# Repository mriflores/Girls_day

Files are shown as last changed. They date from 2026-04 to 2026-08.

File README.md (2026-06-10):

# 433MHz RF Communication Project with ID Filtering & Servo Control

This project implements a wireless communication system between two Arduino boards using 433MHz Radio Frequency modules. It features a custom ID filtering system to ensure messages are processed only by the intended receiver, and allows for remote control of a servo motor.

---

## Hardware Configuration

### Components Required
* **Microcontrollers:** 2x Arduino Uno.
* **RF Kit:** 2x 433MHz Transmitter (FS1000A), 1x 433MHz Receiver (XY-MX-5V).
* **Actuator:** 1x Servo Motor (e.g., SG90, MG996R).
* **Antennas:** 4x 17.3 cm copper wires (Required for range beyond 10cm).

### RF Wiring Diagram

| RF Module | Arduino Pin | Description |
| :--- | :--- | :--- |
| **Transmitter DATA** | D12 | Data Output |
| **Transmitter VCC** | 5V | Power (Up to 12V for range) |
| **Transmitter GND** | GND | Ground |
| **Receiver DATA** | D11 | Data Input |
| **Receiver VCC** | 5V | Power (Must be stable 5V) |
| **Receiver GND** | GND | Ground |

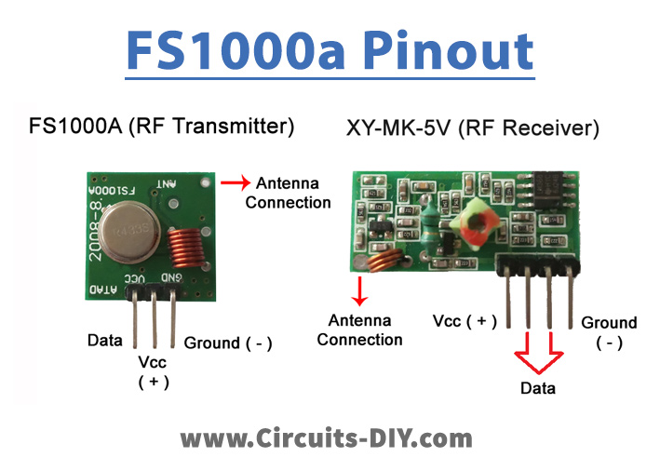
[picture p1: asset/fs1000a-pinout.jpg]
Pinout


### Servo Wiring Diagram

| Servo | Arduino Pin | Description |
| :--- | :--- | :--- |
| **Signal (Orange/Yellow)**| D2 | PWM Control Signal |
| **VCC (Red)** | 5V | Power (External power recommended for larger servos) |
| **GND (Brown/Black)** | GND | Ground |

---

## Technical Implementation & Dependencies

The system relies on specific libraries to manage the communication and motor control without hardware timer conflicts:

* **RadioHead (RH_ASK):** Handles the physical layer bit-streaming, preamble, and CRC error checking for the RF modules. It inherently relies on Arduino's Timer 1.
* **ServoTimer2:** Manages the PWM signals for the servo motor. Using this library instead of the standard Arduino `Servo.h` is necessary to prevent Timer 1 conflicts, ensuring both RF communication and servo movements work seamlessly together.

---

## Features

* **Targeted Messaging:** Uses custom ID prefixes to ensure that only the designated receiver acts on a broadcasted message, ignoring irrelevant data.
* **Remote Actuation:** Wirelessly controls a servo motor, interpreting text strings to execute specific physical movements.
* **Dynamic Pulse Mapping:** Automatically maps standard angle values (0-180 degrees) to microsecond pulse widths for accurate servo positioning.

---

## Command Protocol

The transmitter must format strings with a specific structure for the receiver to validate and act upon them. The structure is: 

`[RECEIVER_ID] [COMMAND]`

### Example Usage:
In this project, the Receiver's ID is set to `100`. Through the Serial Monitor, you can send the following commands:

* **`100 OPEN`**: The receiver parses the ID, confirms a match, and moves the servo to the 90-degree position.
* **`100 CLOSE`**: The receiver parses the ID, confirms a match, and returns the servo to the 0-degree position.

Any message received with an incorrect ID (e.g., `300 OPEN` or just `OPEN`) will be completely ignored by the receiving node.

---

## Important Notes
* **Power Supply:** If the Arduino resets or the RF receiver stops working when the servo moves, it is highly recommended to power the servo with a separate 5V power supply. Remember to connect the ground (GND) of the external power supply to the Arduino's GND.

---

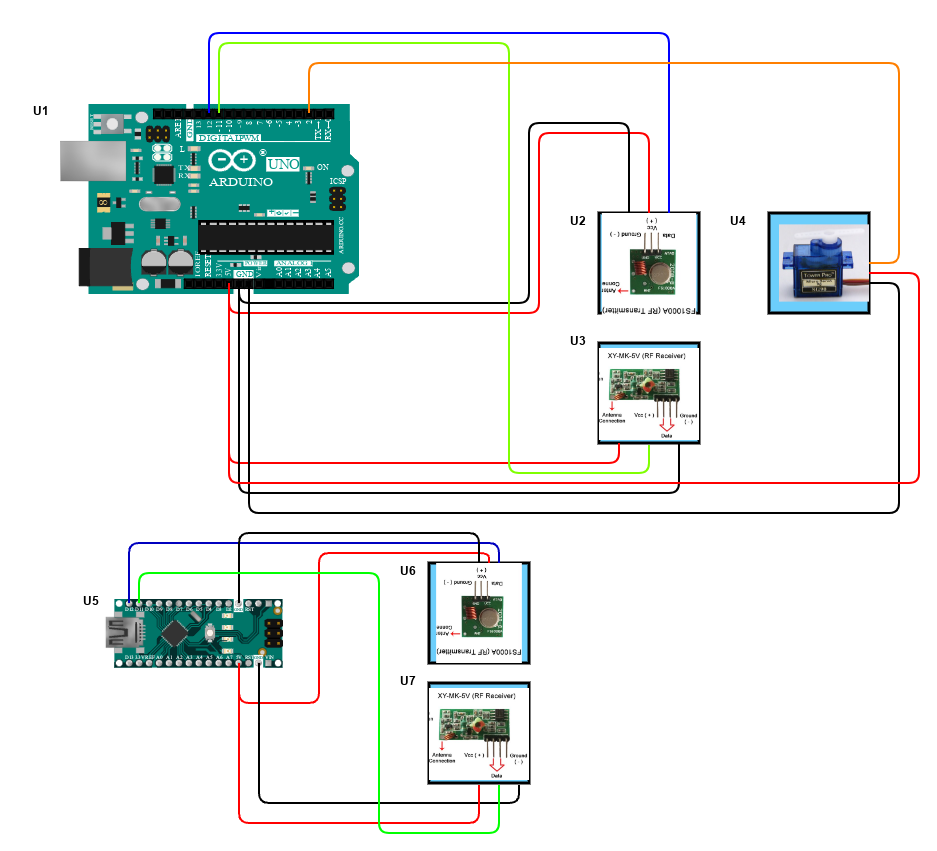
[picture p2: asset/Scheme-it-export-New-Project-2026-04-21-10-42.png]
Schematic Overview


The uploaded image illustrates the specific wiring connections for two separate microcontroller nodes capable of two-way RF communication.

**Node 1** (Top Section)
    This node acts as the primary controller equipped with actuation capabilities.

* Microcontroller: Arduino Uno (U1).

* RF Transmitter (U2 - FS1000A): The Data pin is wired to digital pin D12 (blue wire).

* RF Receiver (U3 - XY-MK-5V): The Data pin is wired to digital pin D11 (green wire).

* Servo Motor (U4): The PWM signal pin is wired to digital pin D2 (orange wire).

Power: All three peripherals (U2, U3, U4) share common 5V (red wires) and Ground (black wires) connections drawn directly from the Arduino Uno.

**Node 2** (Bottom Section)
    This node acts as the secondary transceiver.

* Microcontroller: A compact Arduino board, such as a Nano or Micro (U5).

* RF Transmitter (U6 - FS1000A): The Data pin is wired to digital pin D12 (blue wire).

* RF Receiver (U7 - XY-MK-5V): The Data pin is wired to digital pin D11 (green wire).

Power: Both RF modules draw 5V (red wires) and Ground (black wires) from the compact Arduino board.

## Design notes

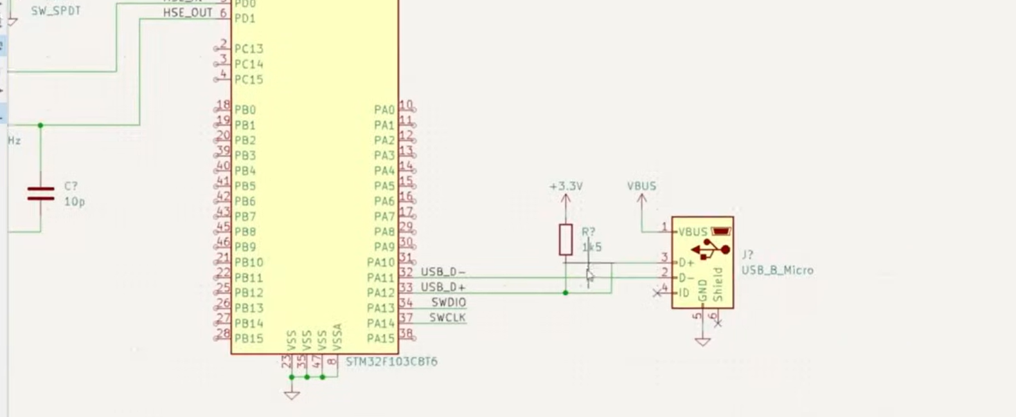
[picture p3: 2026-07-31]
PCB_GIRLS_DAY/SCH_Source_PCB_Girls_Day/Screenshot 2026-07-31 135343.png

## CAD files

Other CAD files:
Box_Grils_Day.f3z

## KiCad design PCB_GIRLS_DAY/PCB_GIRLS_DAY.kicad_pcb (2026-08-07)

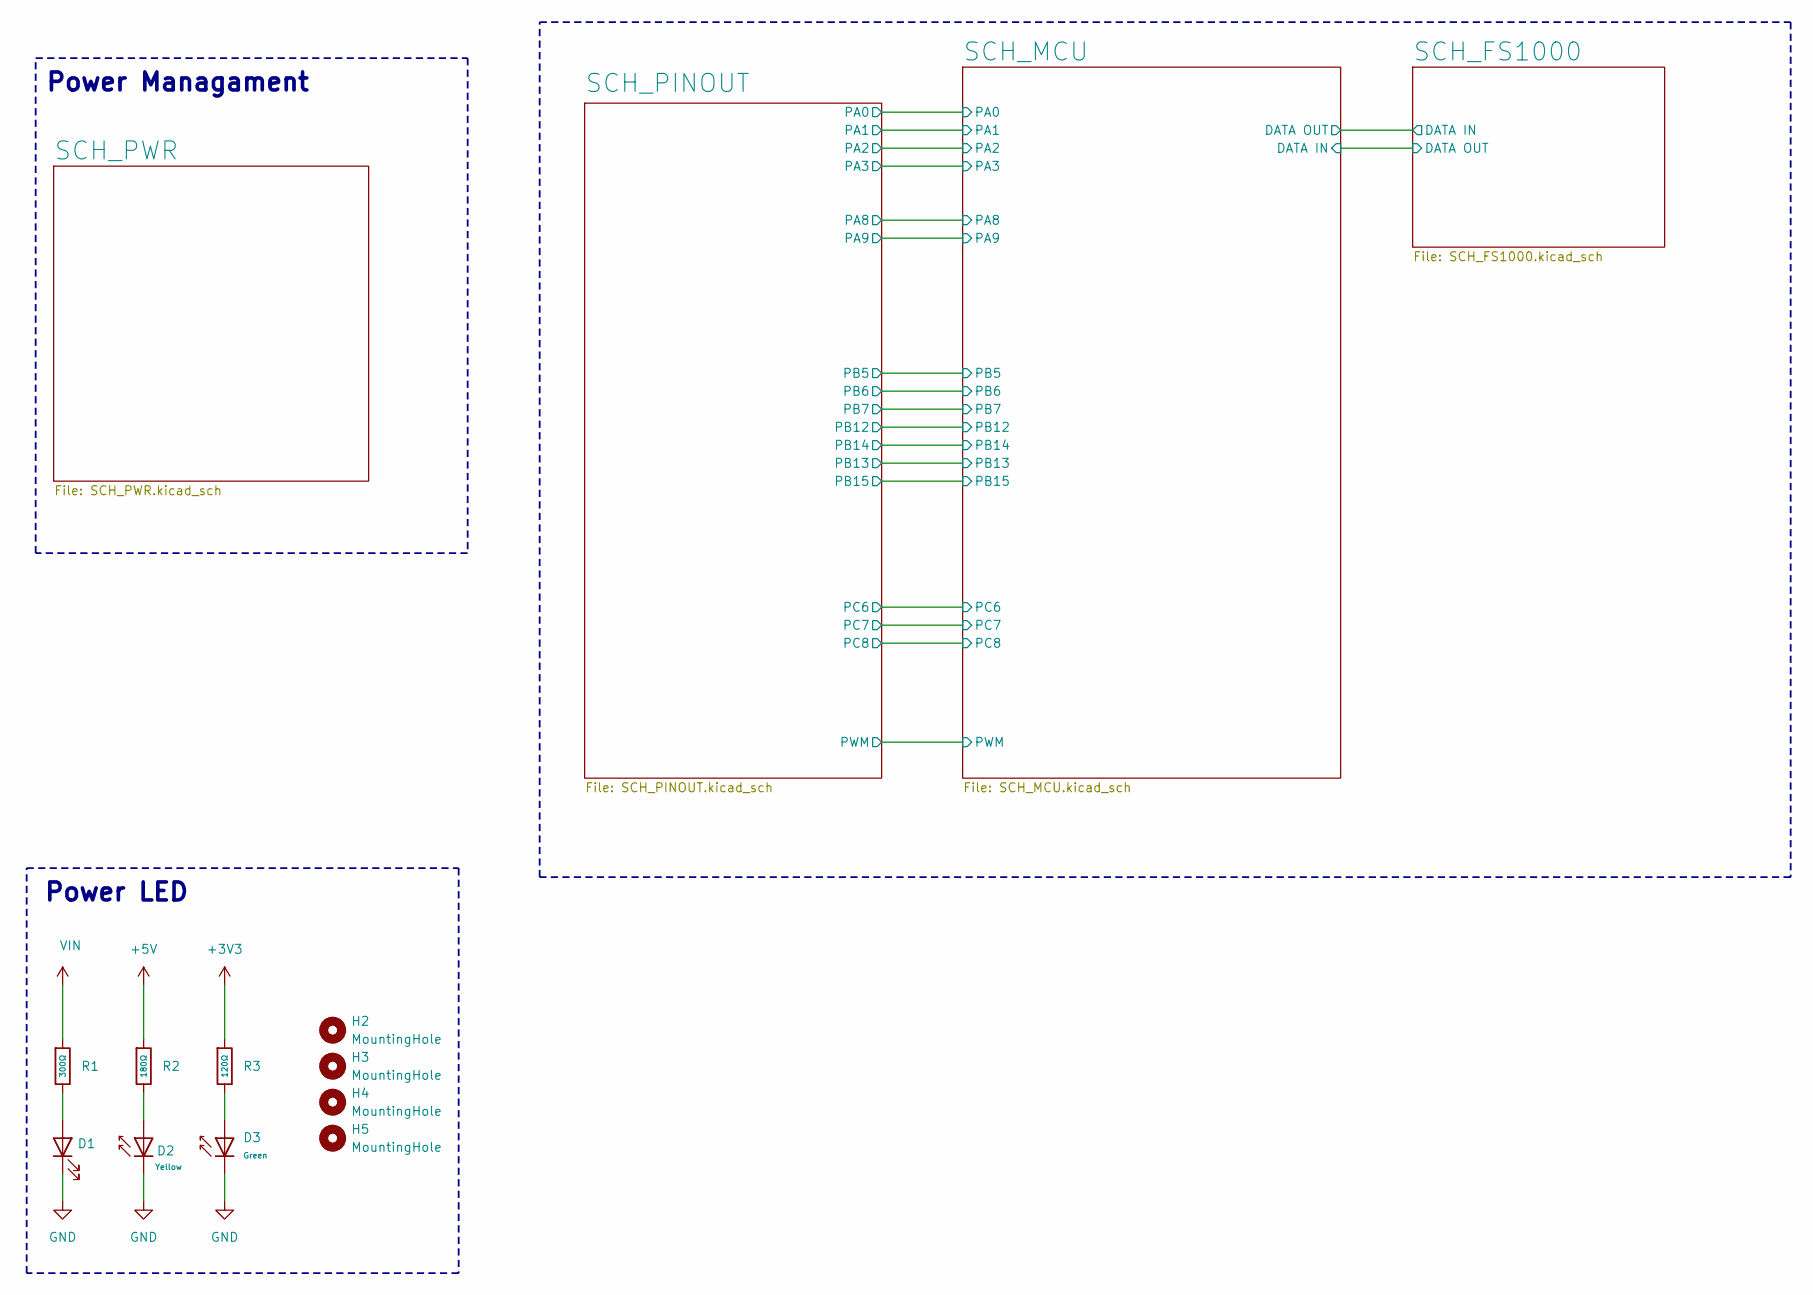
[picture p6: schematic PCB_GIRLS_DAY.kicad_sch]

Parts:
D1: IR26-21C_L110_TR8; LED_1206_3216Metric
D2: Yellow; D_0805; Part KT-0805Y; LCSC C2296
D3: Green; D_0805; Part KT-0805G; LCSC C2297
H2, H3, H4, H5: MountingHole; MountingHole_2.1mm
R1: 300Ω; R_1206; Overload Voltage (Max) 200V; Tolerance ±1%; Part 1206W4F3000T5E; LCSC C17887
R2: 180Ω; R_1206; Overload Voltage (Max) 200V; Tolerance ±1%; Part 1206W4F1800T5E; LCSC C17924
R3: 120Ω; R_0805; Overload Voltage (Max) 150V; Tolerance ±1%; Part 0805W8F1200T5E; LCSC C17437

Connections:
+3V3: R3.1; also elsewhere on the board
+5V: R2.1; also elsewhere on the board
GND: D1.1 (K), D2.1, D3.1; also elsewhere on the board
unnamed: D1.2 (A), R1.2
unnamed: D2.2, R2.2
unnamed: D3.2, R3.2
VIN: R1.1; also elsewhere on the board

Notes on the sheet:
Power Managament
Power LED

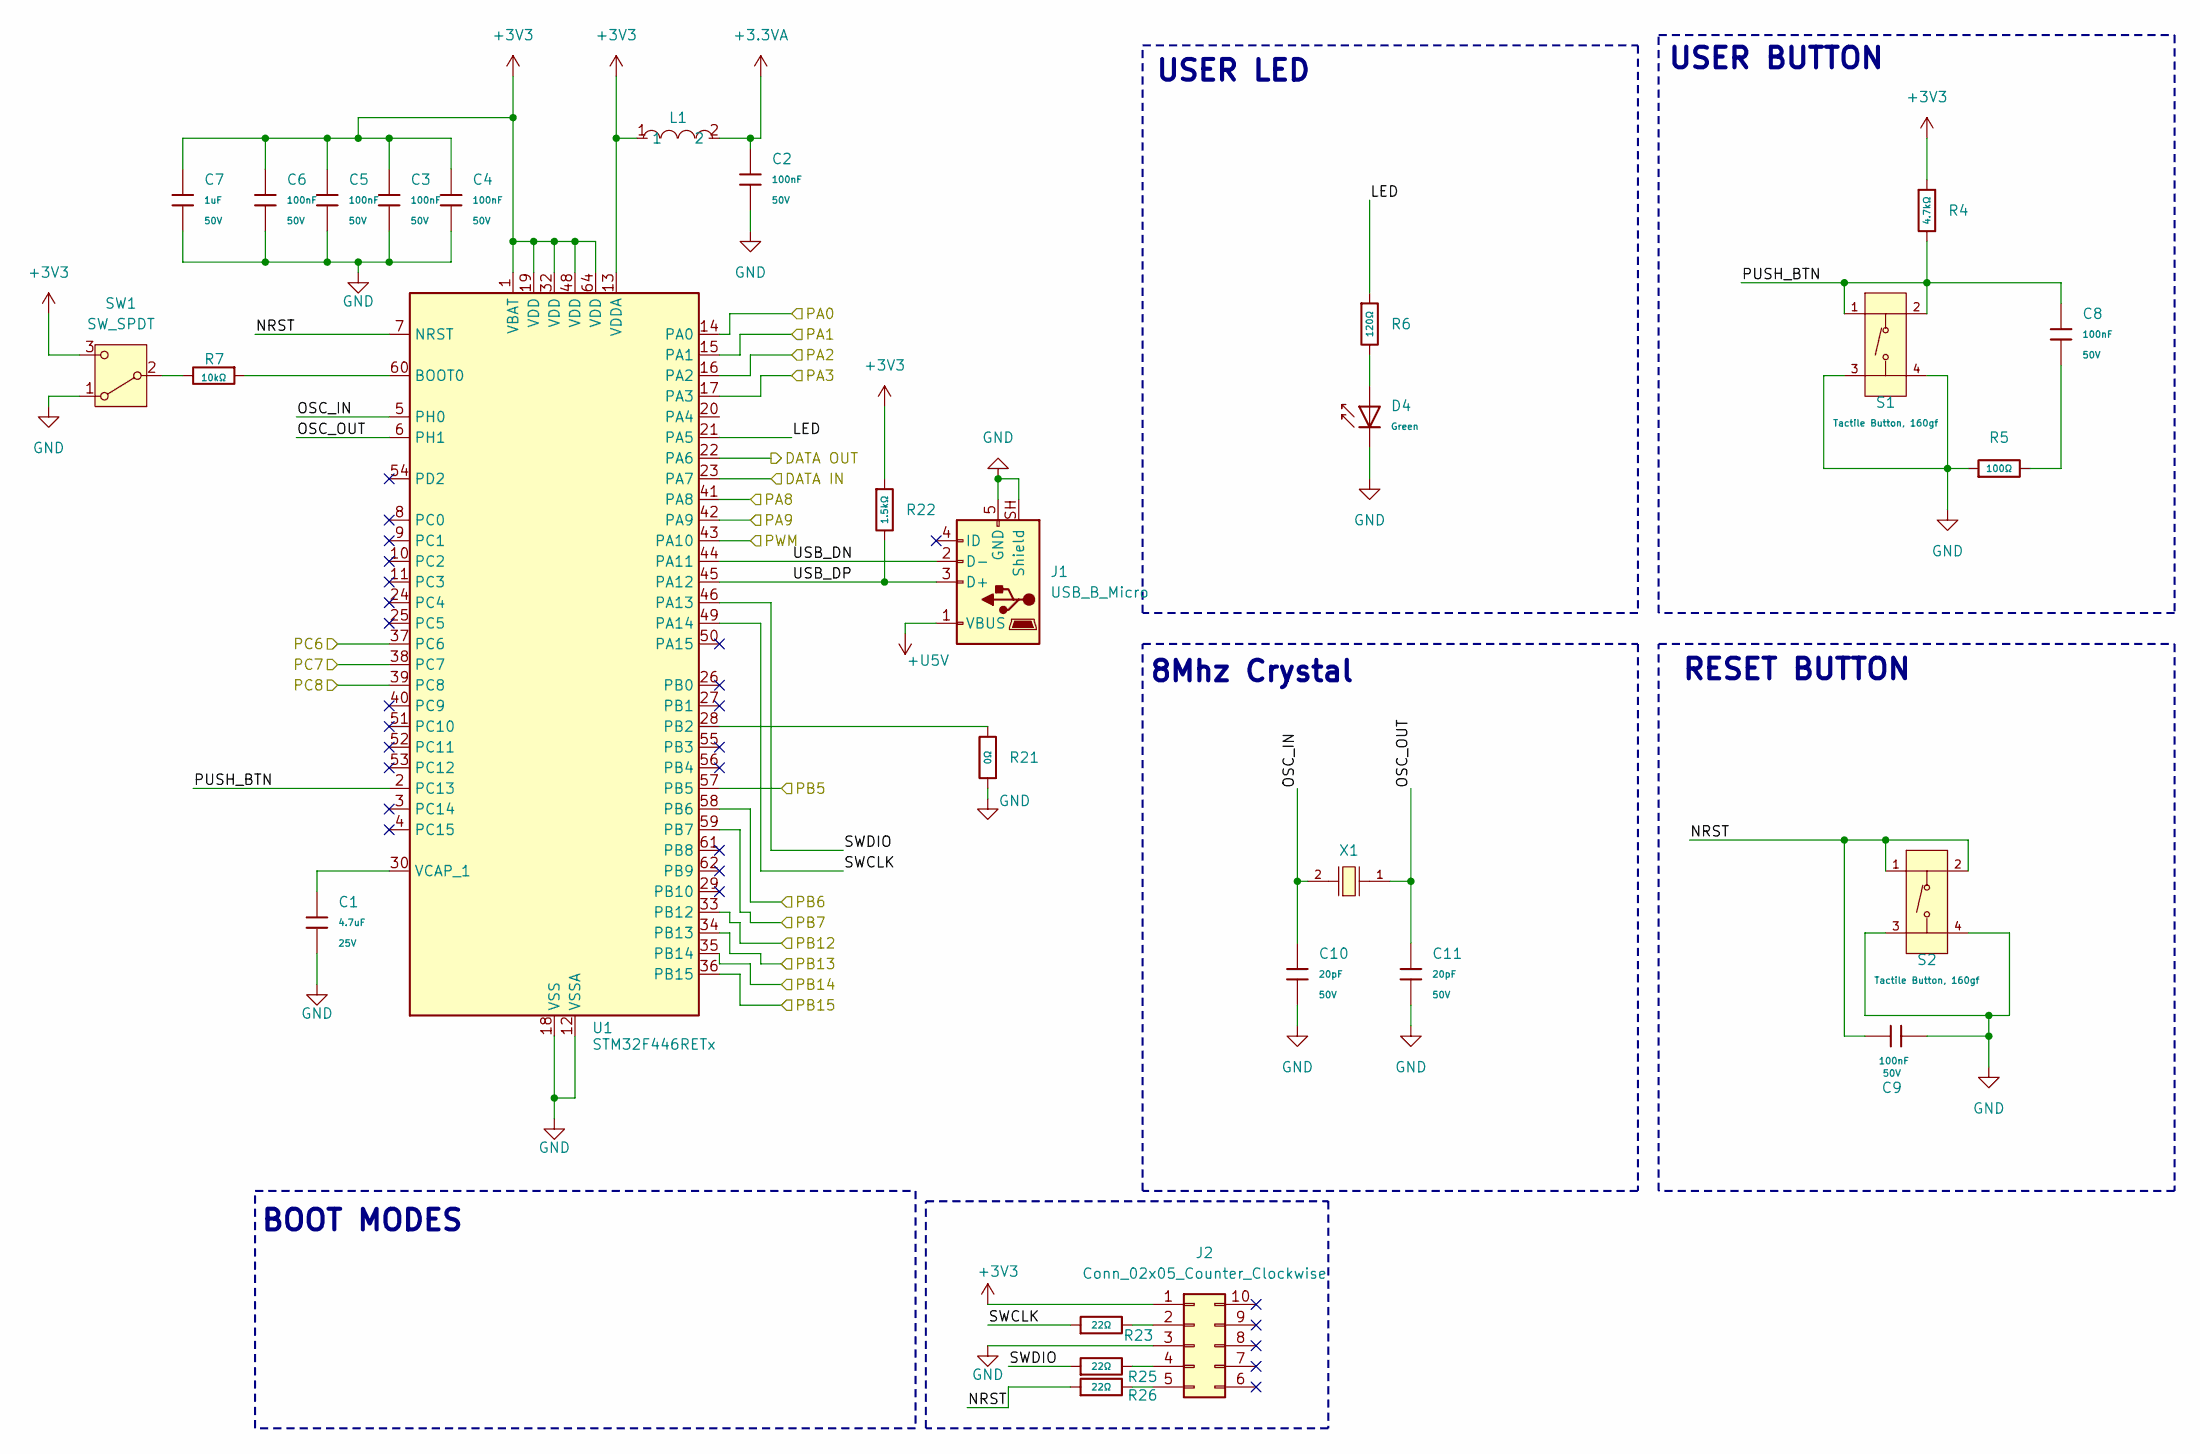
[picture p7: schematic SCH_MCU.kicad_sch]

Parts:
C1: 4.7uF; C_0805; Voltage Rated 25V; Tolerance ±10%; Part CL21A475KAQNNNE; LCSC C1779
C2, C3, C4, C5, C6, C8, C9: 100nF; C_0603; Voltage Rated 50V; Tolerance ±10%; Part CC0603KRX7R9BB104; LCSC C14663
C7: 1uF; C_0603; Voltage Rated 50V; Tolerance ±10%; Part CL10A105KB8NNNC; LCSC C15849
C10, C11: 20pF; C_0603; Voltage Rated 50V; Tolerance ±5%; Part CL10C200JB8NNNC; LCSC C1648
D4: Green; D_0805; Part KT-0805G; LCSC C2297
J1: USB_B_Micro; USB_Micro-B_Wuerth_629105150521
J2: Conn_02x05_Counter_Clockwise; Tag-Connect_TC2050-IDC-FP_2x05_P1.27mm_Vertical
L1: FCM1608KF-601T05; L0603; MPN FCM1608KF-601T05; LCSC Part C133937
R4: 4.7kΩ; R_0603; Overload Voltage (Max) 75V; Tolerance ±1%; Part 0603WAF4701T5E; LCSC C23162
R5: 100Ω; R_0603; Overload Voltage (Max) 75V; Tolerance ±1%; Part 0603WAF1000T5E; LCSC C22775
R6: 120Ω; R_0805; Overload Voltage (Max) 150V; Tolerance ±1%; Part 0805W8F1200T5E; LCSC C17437
R7: 10kΩ; R_0603; Overload Voltage (Max) 75V; Tolerance ±1%; Part 0603WAF1002T5E; LCSC C25804
R21: 0Ω; R_0603; Overload Voltage (Max) 75V; Tolerance ±1%; Part 0603WAF0000T5E; LCSC C21189
R22: 1.5kΩ; R_0603; Overload Voltage (Max) 75V; Tolerance ±1%; Part 0603WAF1501T5E; LCSC C22843
R23, R25, R26: 22Ω; R_0603; Overload Voltage (Max) 75V; Tolerance ±1%; Part 0603WAF220JT5E; LCSC C23345
S1, S2: Tactile Button, 160gf; SW-SMD_4P-L5.1-W5.1-P3.70-LS6.5-TL-2; Voltage Rating (Dc) 12V; Part TS-1187A-B-A-B; LCSC C318884
SW1: SW_SPDT; SW_SPDT_PCM12
U1: STM32F446RETx; LQFP-64_10x10mm_P0.5mm
X1: X50328MSB2GI; CRYSTAL-SMD_L5.0-W3.2; Frequency Tolerance ±10ppm; Part X50328MSB2GI; LCSC C115962

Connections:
+3.3VA: C2.1, L1.2
+3V3: C3.1, C4.1, C5.1, C6.1, C7.1, J2.1, L1.1, R4.1, R22.1, SW1.3 (C), U1.1 (VBAT), U1.13 (VDDA), U1.19 (VDD), U1.32 (VDD), U1.48 (VDD), U1.64 (VDD); also elsewhere on the board
+U5V: J1.1 (VBUS); also elsewhere on the board
/SCH_FS1000/DATA IN: U1.22 (PA6); also elsewhere on the board
/SCH_FS1000/DATA OUT: U1.23 (PA7); also elsewhere on the board
/SCH_MCU/LED: R6.1, U1.21 (PA5)
/SCH_MCU/NRST: C9.2, R26.1, S2.1 (A), S2.2 (B), U1.7 (NRST)
/SCH_MCU/OSC_IN: C10.1, U1.5 (PH0), X1.2
/SCH_MCU/OSC_OUT: C11.1, U1.6 (PH1), X1.1
/SCH_MCU/PA0: U1.14 (PA0); also elsewhere on the board
/SCH_MCU/PA1: U1.15 (PA1); also elsewhere on the board
/SCH_MCU/PA2: U1.16 (PA2); also elsewhere on the board
/SCH_MCU/PA3: U1.17 (PA3); also elsewhere on the board
/SCH_MCU/PA8: U1.41 (PA8); also elsewhere on the board
/SCH_MCU/PA9: U1.42 (PA9); also elsewhere on the board
/SCH_MCU/PB5: U1.57 (PB5); also elsewhere on the board
/SCH_MCU/PB6: U1.58 (PB6); also elsewhere on the board
/SCH_MCU/PB7: U1.59 (PB7); also elsewhere on the board
/SCH_MCU/PB12: U1.33 (PB12); also elsewhere on the board
/SCH_MCU/PB13: U1.34 (PB13); also elsewhere on the board
/SCH_MCU/PB14: U1.35 (PB14); also elsewhere on the board
/SCH_MCU/PB15: U1.36 (PB15); also elsewhere on the board
/SCH_MCU/PC6: U1.37 (PC6); also elsewhere on the board
/SCH_MCU/PC7: U1.38 (PC7); also elsewhere on the board
/SCH_MCU/PC8: U1.39 (PC8); also elsewhere on the board
/SCH_MCU/PUSH_BTN: C8.1, R4.2, S1.1 (A), S1.2 (B), U1.2 (PC13)
/SCH_MCU/PWM: U1.43 (PA10); also elsewhere on the board
/SCH_MCU/SWCLK: R23.1, U1.49 (PA14)
/SCH_MCU/SWDIO: R25.1, U1.46 (PA13)
/SCH_MCU/USB_DN: J1.2 (D-), U1.44 (PA11)
/SCH_MCU/USB_DP: J1.3 (D+), R22.2, U1.45 (PA12)
GND: C1.2, C2.2, C3.2, C4.2, C5.2, C6.2, C7.2, C9.1, C10.2, C11.2, D4.1, J1.5 (GND), J1.SH (Shield), J2.3, R5.1, R21.1, S1.3 (C), S1.4 (D), S2.3 (C), S2.4 (D), SW1.1 (A), U1.12 (VSSA), U1.18 (VSS), U1.31 (VSS), U1.47 (VSS), U1.63 (VSS); also elsewhere on the board
unnamed: C8.2, R5.2
unnamed: D4.2, R6.2
unnamed: J2.2, R23.2
unnamed: J2.4, R25.2
unnamed: J2.5, R26.2
unnamed: R7.2, SW1.2 (B)
unnamed: R7.1, U1.60 (BOOT0)
unnamed: R21.2, U1.28 (PB2)
unnamed: C1.1, U1.30 (VCAP_1)

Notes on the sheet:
USER LED
8Mhz Crystal
BOOT MODES
USER BUTTON
RESET BUTTON

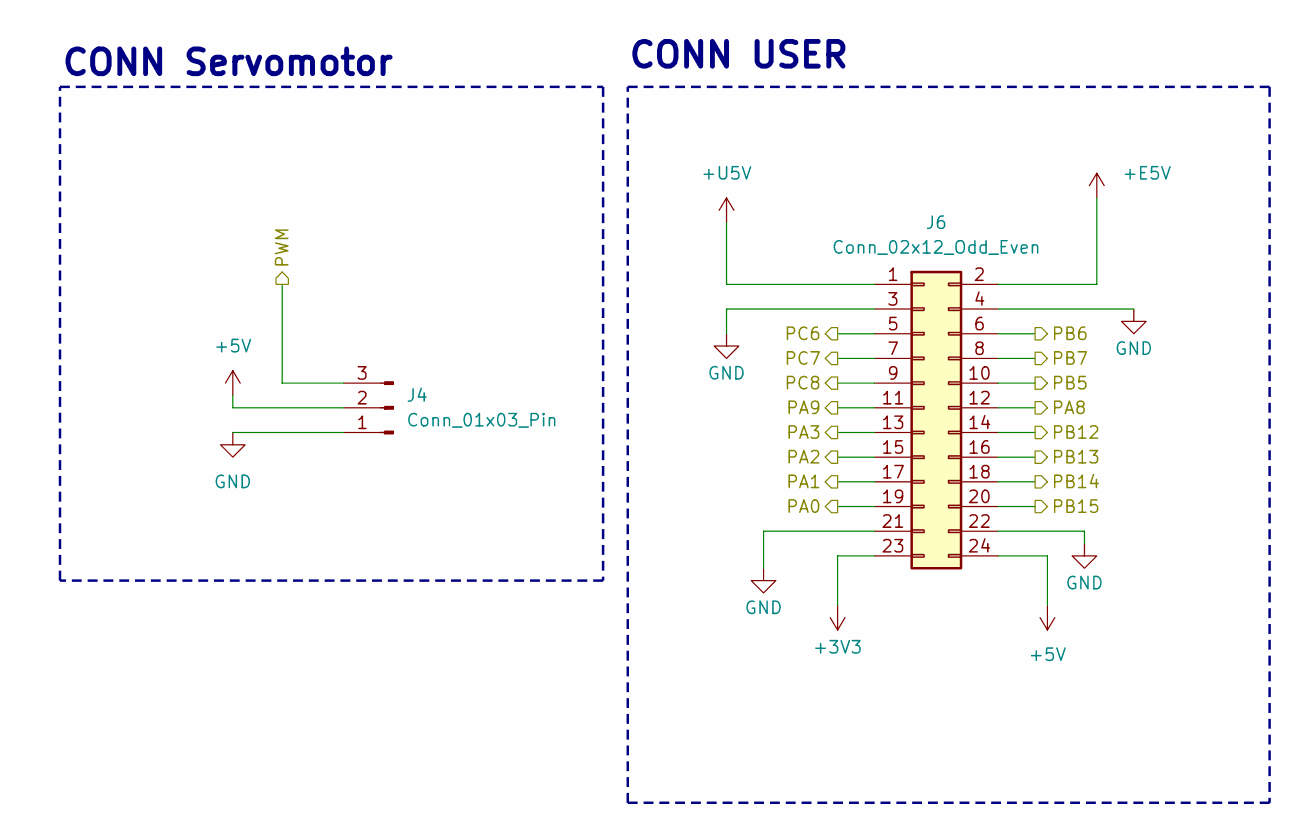
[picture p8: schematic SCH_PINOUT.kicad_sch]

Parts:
J4: Conn_01x03_Pin; PinHeader_1x03_P2.54mm_Vertical
J6: Conn_02x12_Odd_Even; Samtec_HLE-112-02-xx-DV-TE_2x12_P2.54mm_Horizontal

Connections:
+3V3: J6.23; also elsewhere on the board
+5V: J4.2, J6.24; also elsewhere on the board
+E5V: J6.2; also elsewhere on the board
+U5V: J6.1; also elsewhere on the board
/SCH_MCU/PA0: J6.19; also elsewhere on the board
/SCH_MCU/PA1: J6.17; also elsewhere on the board
/SCH_MCU/PA2: J6.15; also elsewhere on the board
/SCH_MCU/PA3: J6.13; also elsewhere on the board
/SCH_MCU/PA8: J6.12; also elsewhere on the board
/SCH_MCU/PA9: J6.11; also elsewhere on the board
/SCH_MCU/PB5: J6.10; also elsewhere on the board
/SCH_MCU/PB6: J6.6; also elsewhere on the board
/SCH_MCU/PB7: J6.8; also elsewhere on the board
/SCH_MCU/PB12: J6.14; also elsewhere on the board
/SCH_MCU/PB13: J6.16; also elsewhere on the board
/SCH_MCU/PB14: J6.18; also elsewhere on the board
/SCH_MCU/PB15: J6.20; also elsewhere on the board
/SCH_MCU/PC6: J6.5; also elsewhere on the board
/SCH_MCU/PC7: J6.7; also elsewhere on the board
/SCH_MCU/PC8: J6.9; also elsewhere on the board
/SCH_MCU/PWM: J4.3; also elsewhere on the board
GND: J4.1, J6.3, J6.4, J6.21, J6.22; also elsewhere on the board

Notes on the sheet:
CONN Servomotor
CONN USER

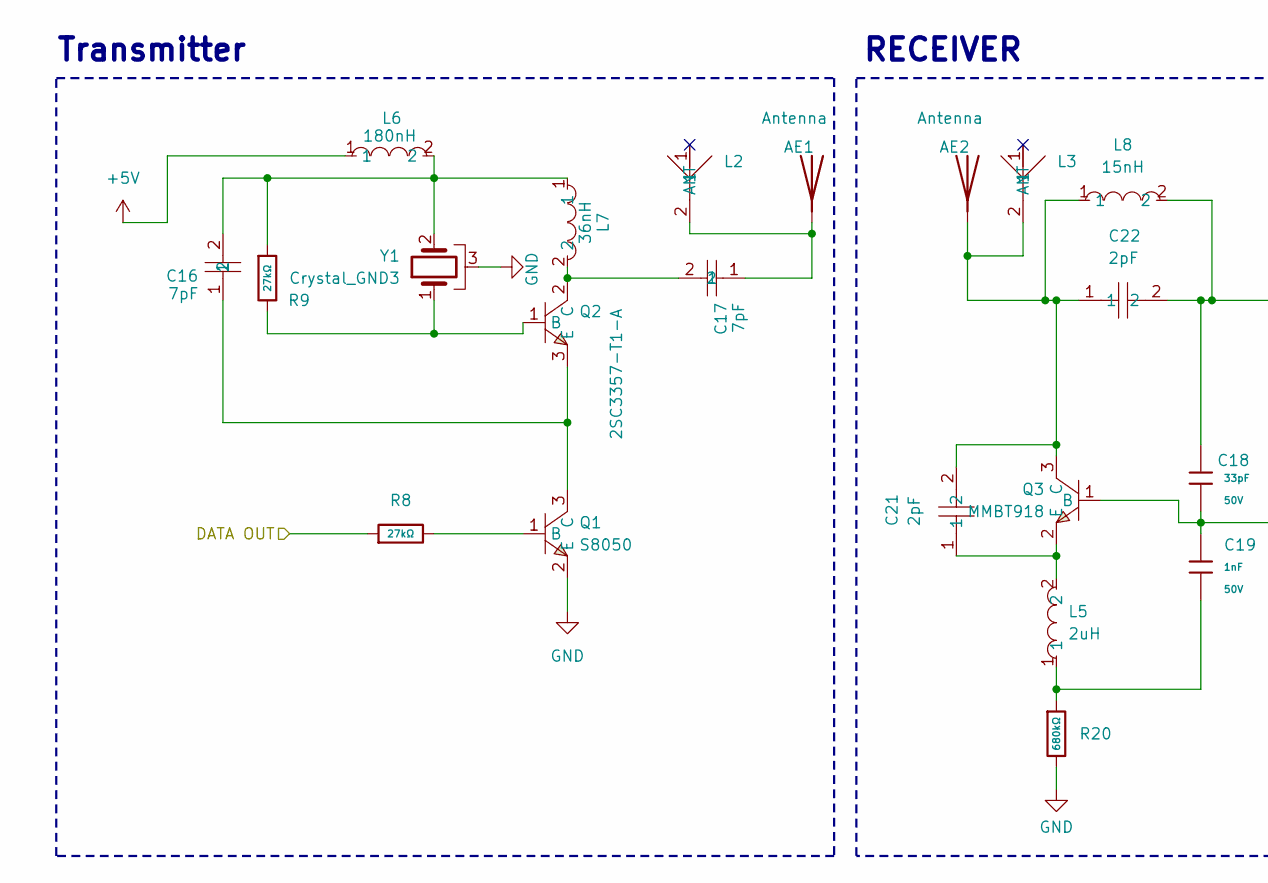
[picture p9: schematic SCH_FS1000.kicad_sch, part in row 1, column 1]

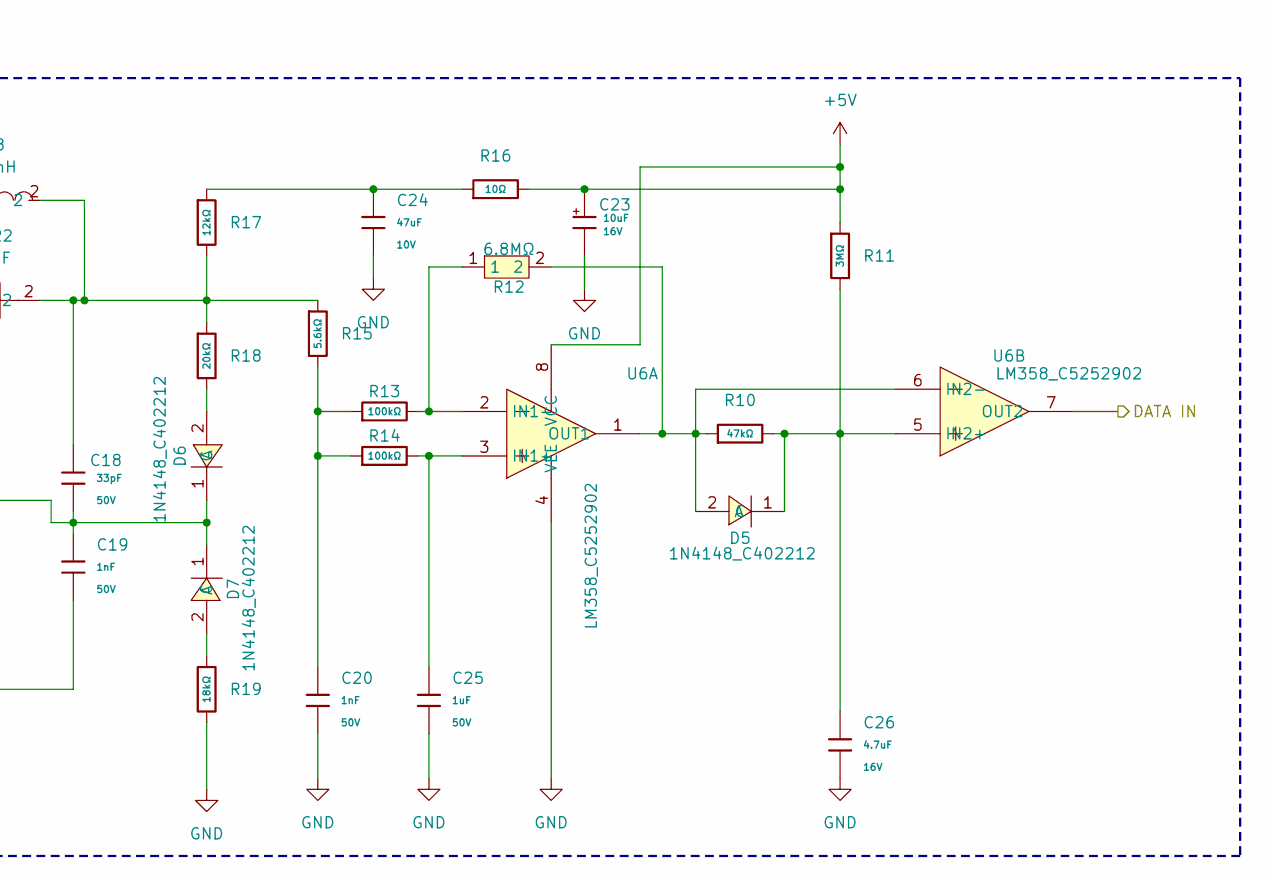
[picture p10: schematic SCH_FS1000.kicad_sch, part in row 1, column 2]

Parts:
AE1, AE2: Antenna; Samtec_HPM-01-01-x-S_Straight_1x01_Pitch5.08mm
C16: 7pF; C_0603_1608Metric; MPN 0603CG7R0C500NT; LCSC Part C1682
C17: 7pF; C_0603_1608Metric_Pad1.08x0.95mm_HandSolder; MPN 0603CG7R0C500NT; LCSC Part C1682
C18: 33pF; C_0603; Voltage Rated 50V; Tolerance ±5%; Part CL10C330JB8NNNC; LCSC C1663
C19, C20: 1nF; C_0603; Voltage Rated 50V; Tolerance ±10%; Part CL10B102KB8NNNC; LCSC C1588
C21, C22: 2pF; C_0603_1608Metric_Pad1.08x0.95mm_HandSolder; MPN CC0603BRNPO9BN2R0; LCSC Part C513620
C23: 10uF; C_CASE-A-3216-18(mm); Tolerance ±10%; Rated Voltage 16V; Part TAJA106K016RNJ; LCSC C7171
C24: 47uF; C_1206; Voltage Rated 10V; Tolerance ±20%; Part CL31A476MPHNNNE; LCSC C96123
C25: 1uF; C_0603; Voltage Rated 50V; Tolerance ±10%; Part CL10A105KB8NNNC; LCSC C15849
C26: 4.7uF; C_0603; Voltage Rated 16V; Tolerance ±10%; Part CL10A475KO8NNNC; LCSC C19666
D5, D6, D7: 1N4148_C402212; DO-35_BD2.0-L4.2-P8.20-D0.5-RD; MPN 1N4148; LCSC Part C402212
L2, L3: BW433MNX1304; ANT-SMD_L130-W42_BW433MNX; MPN BW433MNX1304; LCSC Part C49330093
L5: 2uH; IND-SMD_L10.2-W10.2-LS10.8; MPN IHLP4040DZER2R0M11; LCSC Part C554005
L6: 180nH; IND-SMD_L1.8-W1.2; MPN AISC-0603-R18J-T; LCSC Part C186904
L7: 36nH; IND-SMD_L1.0-W0.5-2; MPN LQW15AN36NG00D; LCSC Part C167476
L8: 15nH; IND-SMD_L1.0-W0.5-2; MPN LQW15AN15NG00D; LCSC Part C98055
Q1: S8050; SOT-23-3_L2.9-W1.3-P1.90-LS2.4-BR; MPN S8050; LCSC Part C916390
Q2: 2SC3357-T1-A; SOT-89-3_L4.5-W2.5-P1.50-LS4.2-BR; MPN 2SC3357-T1-A; LCSC Part C49241781
Q3: MMBT918; SOT-23-3_L2.9-W1.3-P1.90-LS2.4-BR; MPN MMBT918; LCSC Part C184118
R8: 27kΩ; R_0402; Overload Voltage (Max) 50V; Tolerance ±1%; Part 0402WGF2702TCE; LCSC C25771
R9: 27kΩ; R_0603; Overload Voltage (Max) 75V; Tolerance ±1%; Part 0603WAF2702T5E; LCSC C22967
R10: 47kΩ; R_0603; Overload Voltage (Max) 75V; Tolerance ±1%; Part 0603WAF4702T5E; LCSC C25819
R11: 3MΩ; R_0603; Overload Voltage (Max) 75V; Tolerance ±1%; Part 0603WAF3004T5E; LCSC C23156
R12: 6.8MΩ; R1206; MPN FRC1206F6804TS; LCSC Part C3000532
R13, R14: 100kΩ; R_0603; Overload Voltage (Max) 75V; Tolerance ±1%; Part 0603WAF1003T5E; LCSC C25803
R15: 5.6kΩ; R_0603; Overload Voltage (Max) 75V; Tolerance ±1%; Part 0603WAF5601T5E; LCSC C23189
R16: 10Ω; R_0603; Overload Voltage (Max) 75V; Tolerance ±1%; Part 0603WAF100JT5E; LCSC C22859
R17: 12kΩ; R_0603; Overload Voltage (Max) 75V; Tolerance ±1%; Part 0603WAF1202T5E; LCSC C22790
R18: 20kΩ; R_0603; Overload Voltage (Max) 75V; Tolerance ±1%; Part 0603WAF2002T5E; LCSC C4184
R19: 18kΩ; R_0603; Overload Voltage (Max) 75V; Tolerance ±1%; Part 0603WAF1802T5E; LCSC C25810
R20: 680kΩ; R_0603; Overload Voltage (Max) 75V; Tolerance ±1%; Part 0603WAF6803T5E; LCSC C25822
U6: LM358_C5252902; SOP-8_L4.9-W3.9-P1.27-LS6.0-BL; MPN LM358; LCSC Part C5252902
Y1: Crystal_GND3; TO-39-3

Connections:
+5V: C23.1, L6.1, R11.1, R16.2, U6.8 (VCC); also elsewhere on the board
/SCH_FS1000/DATA IN: U6.7 (OUT2); also elsewhere on the board
/SCH_FS1000/DATA OUT: R8.1; also elsewhere on the board
GND: C20.2, C23.2, C24.2, C25.2, C26.2, Q1.2 (E), R19.2, R20.2, U6.4 (VEE), Y1.3; also elsewhere on the board
unnamed: AE1.1 (A_1), C17.1, L2.2 (ANT_2)
unnamed: AE2.1 (A_1), C21.2, C22.1, L3.2 (ANT_2), L8.1, Q3.3 (C)
unnamed: C16.2, L6.2, L7.1, R9.1, Y1.2
unnamed: C18.1, C22.2, L8.2, R15.1, R17.2, R18.1
unnamed: C19.2, L5.1, R20.1
unnamed: C20.1, R13.1, R14.1, R15.2
unnamed: C24.1, R16.1, R17.1
unnamed: D5.2 (A), R10.1, R12.2, U6.1 (OUT1), U6.6 (IN2-)
unnamed: C26.1, D5.1 (C), R10.2, R11.2, U6.5 (IN2+)
unnamed: D6.2 (A), R18.2
unnamed: C18.2, C19.1, D6.1 (C), D7.1 (C), Q3.1 (B)
unnamed: D7.2 (A), R19.1
unnamed: Q1.1 (B), R8.2
unnamed: C16.1, Q1.3 (C), Q2.3 (E)
unnamed: Q2.1 (B), R9.2, Y1.1
unnamed: C17.2, L7.2, Q2.2 (C)
unnamed: C21.1, L5.2, Q3.2 (E)
unnamed: C25.1, R14.2, U6.3 (IN1+)
unnamed: R12.1, R13.2, U6.2 (IN1-)

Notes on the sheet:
Transmitter
RECEIVER

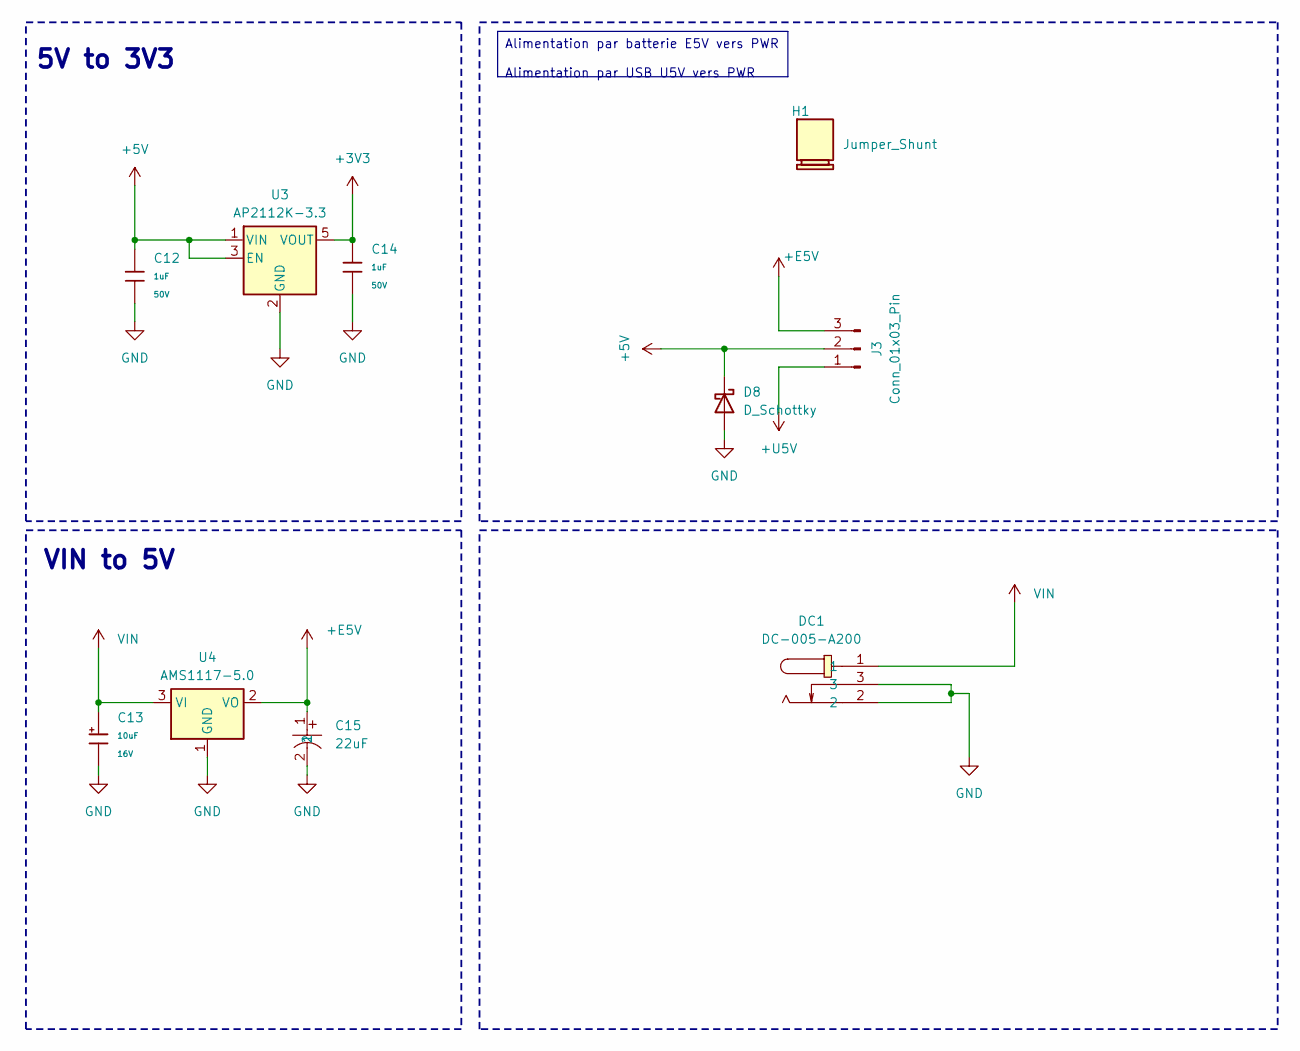
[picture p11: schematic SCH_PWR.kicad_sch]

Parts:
C12, C14: 1uF; C_0603; Voltage Rated 50V; Tolerance ±10%; Part CL10A105KB8NNNC; LCSC C15849
C13: 10uF; C_CASE-A-3216-18(mm); Tolerance ±10%; Rated Voltage 16V; Part TAJA106K016RNJ; LCSC C7171
C15: 22uF; CP_Radial_D4.0mm_P2.00mm; MPN RVT1H220M0605; LCSC Part C72505
D8: D_Schottky; D_SOD-323
DC1: DC-005-A200; DC-IN-TH_DC-005-A200; MPN DC-005-A200; LCSC Part C720557
H1: Jumper_Shunt
J3: Conn_01x03_Pin; PinHeader_1x03_P2.54mm_Vertical
U3: AP2112K-3.3; SOT-23-5
U4: AMS1117-5.0; SOT-223-3_TabPin2

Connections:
+3V3: C14.1, U3.5 (VOUT); also elsewhere on the board
+5V: C12.1, D8.1 (K), J3.2, U3.1 (VIN), U3.3 (EN); also elsewhere on the board
+E5V: C15.1, J3.3, U4.2 (VO); also elsewhere on the board
+U5V: J3.1; also elsewhere on the board
GND: C12.2, C13.2, C14.2, C15.2, D8.2 (A), DC1.2, DC1.3, U3.2 (GND), U4.1 (GND); also elsewhere on the board
VIN: C13.1, DC1.1, U4.3 (VI); also elsewhere on the board

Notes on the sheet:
5V to 3V3
VIN to 5V
Alimentation par batterie E5V vers PWR Alimentation par USB U5V vers PWR

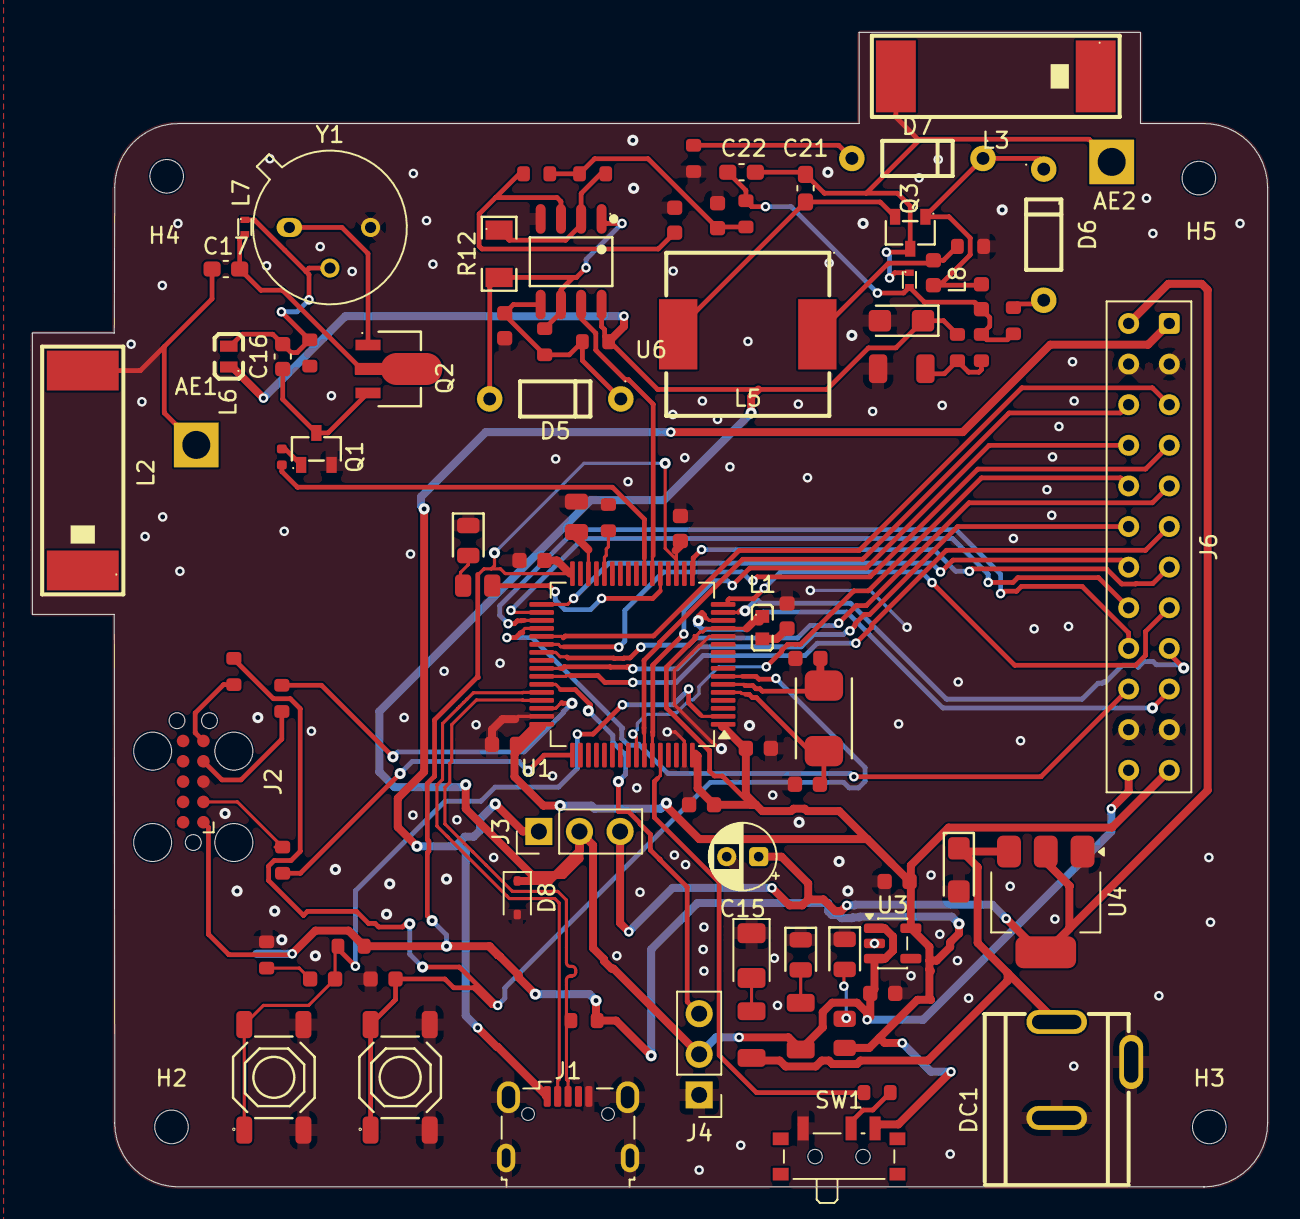
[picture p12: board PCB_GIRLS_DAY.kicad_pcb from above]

Board: 2 copper layers, 77.2 x 72.2 mm, 90 parts (0 on the bottom side), 66 nets.

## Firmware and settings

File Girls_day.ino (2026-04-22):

#include <RH_ASK.h>
#include <SPI.h> // not used, but important for getting fonctions for make it work
#include <ServoTimer2.h>


int pos = 0; 
RH_ASK driver; // Config 2000bps, TX pin 12, RX  pin 11
ServoTimer2 myServo; 

#define rollPin  2
#define Mon_ID "100"
#define RECIVER_ID "300"
#define RADIO_RX_BUFFER 50

void setup() {
    myServo.attach(rollPin);     
    Serial.begin(9600);

    if (!driver.init()) {
        Serial.println("Init not working");
    }
}

void loop() {
    //incPulse();
    sending_message();
    reading_message();
}

void sending_message(){
    if (Serial.available() == 0){
        return;
    }

    String input = Serial.readStringUntil('\n'); 
    if (input != NULL){
        String message_id_temp = String(RECIVER_ID)+" "+input;
        const char* msg = message_id_temp.c_str();

        driver.send((uint8_t *)msg, strlen(msg));
        driver.waitPacketSent();

        Serial.print("Sending: ");
        Serial.println(input.c_str());
    }
}

void reading_message(){
    uint8_t buf[RADIO_RX_BUFFER];
    uint8_t buflen = sizeof(buf);

    if (!driver.recv(buf, &buflen)) {
        return;
    }

    buf[buflen]='\0'; //End of message
    char * id_read = strtok((char*)buf, " ");
    char * message =strtok(NULL,"\0");

    if(id_read == NULL || strcmp(id_read, Mon_ID) != 0){
        return;
    }

    Serial.print("Receive: ");
    Serial.println(message); 
    strupr(message);

    if(strcmp(message, "OPEN") == 0){
        Serial.println("Opening door");
        int angle = 90;
        int anchoPulso = map(angle, 0, 180, 750, 2800);
        myServo.write(anchoPulso);
    } else if(strcmp(message, "CLOSE") == 0){
        Serial.println("Closing door");
        int angle = 0;
        int anchoPulso = map(angle, 0, 180, 750, 2800);
        myServo.write(anchoPulso);
    }
}

int incPulse(){
   if (Serial.available() > 0) {
    
    int angle = Serial.parseInt();

    while(Serial.available() > 0) {
      Serial.read();
    }
    
    
    if (angle >= 0 && angle <= 180) {
      Serial.print("Moving servo: ");
      Serial.print(angle);
      Serial.println(" degrees.");
      
    
      int anchoPulso = map(angle, 0, 180, 750, 2800);
      
      myServo.write(anchoPulso);
      
    } else {
      Serial.println("Error: angle out of range");
    }
  } 
}

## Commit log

2026-04-02 Add pro-tip for antenna wire soldering
    Added a pro-tip for improving signal resonance.
2026-04-17 Enhance README with servo control details
    Updated README to include servo control features and wiring diagrams.
2026-04-22 Update RF Kit and Antenna requirements in README
2026-04-22 Box in Fusion360
    [Box_Grils_Day.f3z]
2026-06-02 Correct data pin descriptions in RF wiring diagram
2026-06-18 Kicad - PCB avant routage
    [PCB_GIRLS_DAY.kicad_pcb, PCB_GIRLS_DAY.kicad_sch, SCH_FS1000.kicad_sch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]
2026-08-07 PCB revision Cyprien
    [PCB_GIRLS_DAY.kicad_pcb, PCB_GIRLS_DAY.kicad_sch, SCH_FS1000.kicad_sch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]
